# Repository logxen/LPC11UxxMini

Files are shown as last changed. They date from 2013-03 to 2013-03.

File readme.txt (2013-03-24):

LPC11Uxx Mini
----------------------------------------------------------------------------------

This is a basic breakout board for the NXP LPC11U24 ARM Cortex-M0 microcontroller 
with usb. It has a similar pinout and form factor to an Arduino Mini. However, it
is a bit longer to accomodate the usb and isp button.

The MCP1252 vreg accepts from 2.5V to 5.5V for running off the RAW pin when usb is 
not connected. When usb is connected the RAW pin provides access to the 'raw' 5V 
usb power. The vreg provides 120mA of 3.3V to run the mcu and some low power 
accessories connected to the VCC pin.

Features:

* program via usb msc (i.e. drag'n'drop new rom to update code)
* on board 3.3V buck/boost voltage regulator
* 22 digital gpio pins including uart, spi, i2c and 8 adc pins
* power indication led and user led (user led is connected to gpio pin D9)
* reset button and isp/user button (isp button is held at boot to enter 
        programming mode and otherwise may be used by user code)

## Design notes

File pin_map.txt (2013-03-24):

Pin	Label	ARM_PIN	Alternate Functions			Proposed Micro Printer Pinout
01	TXD	P0_19	TXD,CT32B0_MAT1				
02	RXD	P0_18	RXD,CT32B0_MAT0				
03	RST	P0_0	RST					
04	GND							
05	D2	P1_19	DTR,SSEL1				ALPHA_EN
06	D3	P0_17	RTS,CT32B0_CAP0,SCLK			ALPHA_DIR
07	D4	P1_15	DCD,CT16B0_MAT2,SCK1			ALPHA_STEP
08	D5	P0_23	AD7					BETA_EN
09	D6	P0_20	CT16B1_CAP0				BETA_DIR
10	D7	P0_2	CT16B0_CAP0,SSEL0			BETA_STEP
11	D8	P0_21	CT16B1_MAT0,MOSI1			GAMMA_EN
12	D9	P0_7	CTS					STATUS_LED
         -This pin drives the status led (LED2)			
13	D10	P0_22	AD6,CT16B1_MAT1,MISO1			GAMMA_DIR
14	MOSI	P0_9	CT16B0_MAT1,MOSI0			GAMMA_STEP
15	MISO	P0_8	CT16B0_MAT0,MISO0			HOTEND
16	SCK	P0_10	CT16B0_MAT2,SCK0	SWCLK		EXTRUDER_EN
17	AD0	P0_11	CT32B0_MAT3		TDI		EXTRUDER_DIR
18	AD1	P0_12	CT32B1_CAP0		TMS		EXTRUDER_STEP
19	AD2	P0_13	CT32B1_MAT0		TDO		ALPHA_LIMIT
20	AD3	P0_14	CT32B1_MAT1		TRST		BETA_LIMIT
21	VCC							
         -The onboard regulator provides 3.3V at up to 120mA
          to power the mcu and small accessories
22	RST	P0_0	RST					
23	GND							
24	RAW							
         -This pin breaks out the raw power from usb OR 
          allows the device to be powered by 2.5V-5.5V
xx	SDA	P0_5	SDA					
xx	SCL	P0_3	SCL					
xx	AD4	P0_15	CT32B1_MAT2		SWDIO		THERMISTOR
xx	AD5	P0_16	CT32B1_MAT3		WAKEUP		GAMMA_LIMIT

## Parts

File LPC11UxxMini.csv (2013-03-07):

Digi-Key Part Number | Manufacturer | Manufacturer Part Number | Customer Reference | Quantity 1 | Quantity 2 | Quantity 3 | Description | Comments | RoHS Status | Lead Free Status | REACH Status
450-1759-1-ND | TE CONNECTIVITY ALCOSWITCH (VA) | FSM4JSMATR |  | 2 | 0 | 0 | SWITCH TACTILE SPST-NO 0.05A 12V | Alternate Packaging Exists | RoHS Compliant | Lead free | Unaffected Aug-2011
568-8009-1-ND | NXP SEMICONDUCTORS (VA) | BC857B,235 |  | 1 | 0 | 0 | TRANSISTOR PNP 45V 100MA SOT23 | Alternate Packaging Exists | RoHS Compliant | Lead free | Unaffected Jul-2011
B0540WSDICT-ND | DIODES INC (VA) | B0540WS-7 |  | 1 | 0 | 0 | DIODE SCHOTTKY 40V 500MA SOD323 | Alternate Packaging Exists | RoHS Compliant | Lead free | Unaffected Jun-2012
609-4613-1-ND | FCI (VA) | 10118192-0001LF | MICROUSB-B CONNECTOR | 2 | 0 | 0 | CONN USB MICRO B RECPT SMT R/A | Alternate Packaging Exists | RoHS Compliant | Lead free | Unaffected Jun-2011
MCP1252-33X50I/MS-ND | MICROCHIP TECHNOLOGY | MCP1252-33X50I/MS | VREG | 1 | 0 | 0 | IC REG MULTI CONFIG 0.12A 8MSOP | Alternate Packaging Exists | RoHS Compliant | Lead free | Unaffected Jun-2012
887-1487-1-ND | TXC CORPORATION (VA) | 8Z-12.000MAAJ-T | 12MHZ CRYSTAL | 1 | 0 | 0 | CRYSTAL 12.000MHZ 18PF SMD | Alternate Packaging Exists | RoHS Compliant | Lead free | Unaffected Nov-2011
P330GCT-ND | PANASONIC ELECTRONIC COMPONENTS (VA) | ERJ-3GEYJ331V |  | 1 | 0 | 0 | RES 330 OHM 1/10W 5% 0603 SMD | Alternate Packaging Exists | RoHS Compliant | Lead free | Not Available
P200GCT-ND | PANASONIC ELECTRONIC COMPONENTS (VA) | ERJ-3GEYJ201V |  | 1 | 0 | 0 | RES 200 OHM 1/10W 5% 0603 SMD | Alternate Packaging Exists | RoHS Compliant | Lead free | Not Available
P1.5KGCT-ND | PANASONIC ELECTRONIC COMPONENTS (VA) | ERJ-3GEYJ152V |  | 1 | 0 | 0 | RES 1.5K OHM 1/10W 5% 0603 SMD | Alternate Packaging Exists | RoHS Compliant | Lead free | Not Available
P10KGCT-ND | PANASONIC ELECTRONIC COMPONENTS (VA) | ERJ-3GEYJ103V |  | 2 | 0 | 0 | RES 10K OHM 1/10W 5% 0603 SMD | Alternate Packaging Exists | RoHS Compliant | Lead free | Not Available
P33GCT-ND | PANASONIC ELECTRONIC COMPONENTS (VA) | ERJ-3GEYJ330V |  | 2 | 0 | 0 | RES 33 OHM 1/10W 5% 0603 SMD | Alternate Packaging Exists | RoHS Compliant | Lead free | Not Available
P3.0KGCT-ND | PANASONIC ELECTRONIC COMPONENTS (VA) | ERJ-3GEYJ302V |  | 1 | 0 | 0 | RES 3.0K OHM 1/10W 5% 0603 SMD | Alternate Packaging Exists | RoHS Compliant | Lead free | Not Available
P24KGCT-ND | PANASONIC ELECTRONIC COMPONENTS (VA) | ERJ-3GEYJ243V |  | 1 | 0 | 0 | RES 24K OHM 1/10W 5% 0603 SMD | Alternate Packaging Exists | RoHS Compliant | Lead free | Not Available
P100GCT-ND | PANASONIC ELECTRONIC COMPONENTS (VA) | ERJ-3GEYJ101V |  | 1 | 0 | 0 | RES 100 OHM 1/10W 5% 0603 SMD | Alternate Packaging Exists | RoHS Compliant | Lead free | Not Available
475-1409-1-ND | OSRAM OPTO SEMICONDUCTORS INC(VA) | LG Q971-KN-1 |  | 1 | 0 | 0 | LED CHIPLED 570NM GREEN 0603 SMD | Alternate Packaging Exists | RoHS Compliant | Lead free | Unaffected Aug-2011
475-2558-1-ND | OSRAM OPTO SEMICONDUCTORS INC(VA) | LY Q976-P1S2-36 |  | 1 | 0 | 0 | LED CHIPLED 587NM YLW 0603 SMD | Alternate Packaging Exists | RoHS Compliant | Lead free | Unaffected Aug-2011
568-8523-ND | NXP SEMICONDUCTORS | LPC11U24FHI33/301, |  | 1 | 0 | 0 | MCU USB 33HVQFN |  | RoHS Compliant | Lead free | Unaffected Jul-2011
490-1409-1-ND | MURATA ELECTRONICS (VA) | GRM1885C1H180JA01D |  | 4 | 0 | 0 | CAP CER 18PF 50V 5% NP0 0603 | Alternate Packaging Exists | RoHS Compliant | Lead free | Unaffected Jul-2011
311-1365-1-ND | YAGEO (VA) | CC0805KKX7R7BB105 |  | 1 | 0 | 0 | CAP CER 1UF 16V 10% X7R 0805 | Alternate Packaging Exists | RoHS Compliant | Lead free | Unaffected Sep-2011
587-2596-1-ND | TAIYO YUDEN (VA) | LMK316B7106KL-TD |  | 2 | 0 | 0 | CAP CER 10UF 10V 10% X7R 1206 | Alternate Packaging Exists | RoHS Compliant | Lead free | Unaffected Nov-2009

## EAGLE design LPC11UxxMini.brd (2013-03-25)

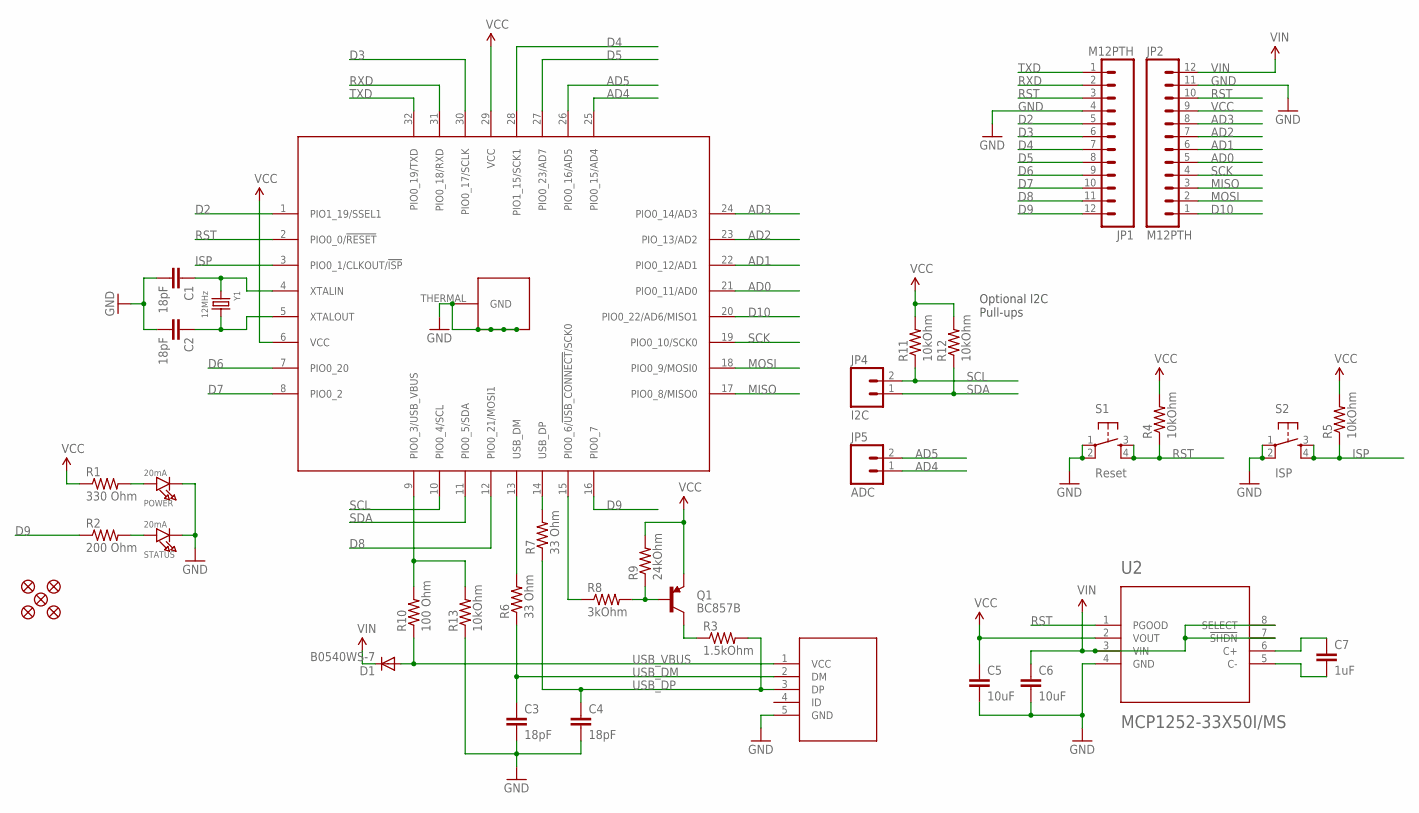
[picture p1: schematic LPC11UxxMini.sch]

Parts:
C1, C2, C3, C4: 18pF; 0603-CAP
C5, C6: 10uF; 1206
C7: 1uF; 0805
D1: B0540WS-7; SOD-323
JP1, JP2: M12PTH; 1X12
JP3, JP6, JP7, JP8, JP9: FIDUCIALUFIDUCIAL; MICRO-FIDUCIAL
JP4: I2C; 1X02
JP5: ADC; 1X02
POWER: 20mA; CHIPLED_0603_NOOUTLINE
Q1: BC857B; SOT23-3
R1: 330 Ohm; 0402-RES
R2: 200 Ohm; 0402-RES
R3: 1.5kOhm; 0402-RES
R4, R5, R11, R12, R13: 10kOhm; 0402-RES
R6, R7: 33 Ohm; 0402-RES
R8: 3kOhm; 0402-RES
R9: 24kOhm; 0402-RES
R10: 100 Ohm; 0402-RES
S1: Reset; TACTILE_SWITCH_SMD
S2: ISP; TACTILE_SWITCH_SMD
STATUS: 20mA; CHIPLED_0603_NOOUTLINE
U1: LPC11Uxx; HVQFN32-5X5_3MMTHERMAL
U2: MCP1252-33X50I/MS; MSOP8_0.65MM
U$1: USB-MICROB-SMDRECEPT; USB-MICROB-RECEPT
Y1: 12MHz; CRYSTAL_2.5X2

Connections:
AD0: JP2.5, U1.21 (PIO0_11/AD0)
AD1: JP2.6, U1.22 (PIO0_12/AD1)
AD2: JP2.7, U1.23 (PIO_13/AD2)
AD3: JP2.8, U1.24 (PIO0_14/AD3)
AD4: JP5.1, U1.25 (PIO0_15/AD4)
AD5: JP5.2, U1.26 (PIO0_16/AD5)
D2: JP1.5, U1.1 (PIO1_19/SSEL1)
D3: JP1.6, U1.30 (PIO0_17/SCLK)
D4: JP1.7, U1.28 (PIO1_15/SCK1)
D5: JP1.8, U1.27 (PIO0_23/AD7)
D6: JP1.9, U1.7 (PIO0_20)
D7: JP1.10, U1.8 (PIO0_2)
D8: JP1.11, U1.12 (PIO0_21/MOSI1)
D9: JP1.12, R2.1, U1.16 (PIO0_7)
D10: JP2.1, U1.20 (PIO0_22/AD6/MISO1)
GND: C1.2, C2.2, C3.2, C4.2, C5.2, C6.2, JP1.4, JP2.11, POWER.C, R13.1, S1.1, S1.2, S2.1, S2.2, STATUS.C, U1.THERMAL (GND), U1.THERMAL@1 (GND), U1.THERMAL@2 (GND), U1.THERMAL@3 (GND), U1.THERMAL@4 (GND), U2.4 (GND), U$1.5 (GND)
ISP: R5.1, S2.3, S2.4, U1.3 (PIO0_1/CLKOUT/!ISP!)
MC_USB_DM: R6.2, U1.13 (USB_DM)
MC_USB_DP: R7.2, U1.14 (USB_DP)
MC_USB_VBUS: R10.2, R13.2, U1.9 (PIO0_3/USB_VBUS)
MISO: JP2.3, U1.17 (PIO0_8/MISO0)
MOSI: JP2.2, U1.18 (PIO0_9/MOSI0)
POWER_LED_RESISTOR: POWER.A, R1.2
PWRREG_C+: C7.1, U2.6 (C+)
PWRREG_C-: C7.2, U2.5 (C-)
RST: JP1.3, JP2.10, R4.1, S1.3, S1.4, U1.2 (PIO0_0/!RESET!), U2.1 (PGOOD)
RXD: JP1.2, U1.31 (PIO0_18/RXD)
SCK: JP2.4, U1.19 (PIO0_10/SCK0)
SCL: JP4.2, R11.1, U1.10 (PIO0_4/SCL)
SDA: JP4.1, R12.1, U1.11 (PIO0_5/SDA)
STATUS_LED_RESISTOR: R2.2, STATUS.A
TXD: JP1.1, U1.32 (PIO0_19/TXD)
USB_CONNECT: R8.1, U1.15 (PIO0_6/!USB_CONNECT!/SCK0)
USB_CONNECT_BASE: Q1.1 (B), R8.2, R9.1
USB_CONNECT_COLLECTOR: Q1.3 (C), R3.1
USB_DM: C3.1, R6.1, U$1.2 (DM)
USB_DP: C4.1, R3.2, R7.1, U$1.3 (DP)
USB_VBUS: D1.2 (A), R10.1, U$1.1 (VCC)
VCC: C5.1, JP2.9, Q1.2 (E), R1.1, R4.2, R5.2, R9.2, R11.2, R12.2, U1.6 (VCC), U1.29 (VCC), U2.2 (VOUT)
VIN: C6.1, D1.1 (C), JP2.12, U2.3 (VIN), U2.7 (!SHDN), U2.8 (SELECT)
XTALIN: C1.1, U1.4 (XTALIN), Y1.1
XTALOUT: C2.1, U1.5 (XTALOUT), Y1.3 (2)

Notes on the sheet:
Optional I2C Pull-ups

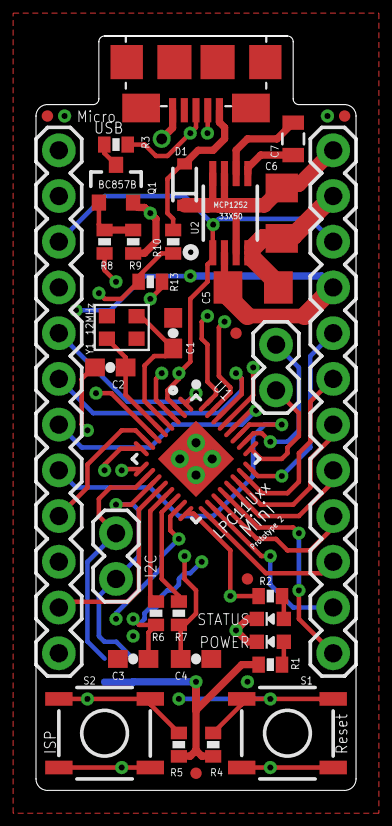
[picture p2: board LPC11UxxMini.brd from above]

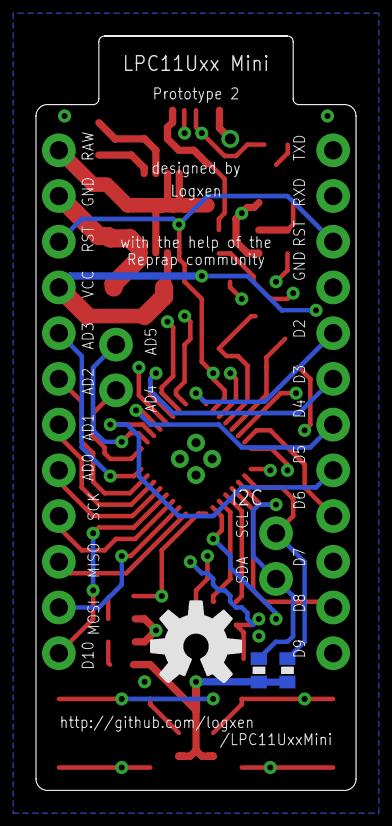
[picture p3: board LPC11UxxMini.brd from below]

Board: 4 copper layers, 17.8 x 41.9 mm, 40 parts (3 on the bottom side), 42 nets.

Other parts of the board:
U$4: OSHW-LOGO-M

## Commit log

2013-03-07 Initial commit (Prototype 1)
    [LPC11UxxMini.brd, LPC11UxxMini.csv, LPC11UxxMini.sch]
2013-03-24 Squished to true Arduino Pro Mini form factor (Prototype 2)
    also added pin_map.txt
    [LPC11UxxMini.brd, LPC11UxxMini.sch]
2013-03-24 Added BoM
    [LPC11UxxMini (2).csv]
2013-03-24 Removed extra BoM file
    [LPC11UxxMini (2).csv]
2013-03-25 Added pull-down to P0_3 USB_VBUS
    leaving P0_3 floating does not seem to reliably select serial
    programming mode vs. usb programming mode, so a 10k pull-down was added
    to assert serial mode when usb power is not present.
    [LPC11UxxMini.brd, LPC11UxxMini.sch]

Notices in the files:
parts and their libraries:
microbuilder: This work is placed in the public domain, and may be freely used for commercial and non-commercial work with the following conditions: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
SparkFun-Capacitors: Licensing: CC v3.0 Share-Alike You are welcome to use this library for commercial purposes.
